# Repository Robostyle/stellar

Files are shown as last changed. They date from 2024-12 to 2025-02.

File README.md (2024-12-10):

<picture>
    Stellar logo
</picture>

# Stellar split Keyboard

- Onshape model can be found [here](https://cad.onshape.com/documents/9f0ec04623bf66083821a7a0/w/c0bdf5da89aae74babc87fd1/e/22223dd23d8e8db672986c41)

# TODO

## PCB

- revision/made text is mirrored on `laR`.
- add silkscreen text for identifying the key, e.g. SW1, etc.
- set rotation on pinky to 10° instead to 5°.
- move the extra row next to the pinky column a bit up (next to the homerow?).

## Inspiration

- https://github.com/urob/zmk-config

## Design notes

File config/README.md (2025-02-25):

# Stellar ZMK firmware

## Building the firmware

The Stellar keyboard uses [ZMK](https://zmk.dev/) firmware which is powered by the [Zephyr :tm: Project ](https://zephyrproject.org/) Real Time Operating System (RTOS).

There are two ways to build, either through a GitHub action, or with a local toolchain.

### Local builds

To build the firmware, see the instructions under the "Development' section. You need to setup ZMK by following the instructions under "Native" [here](https://zmk.dev/docs/development/local-toolchain/setup/native). This only needs to be done once, if you leave the Python virtual environment, source the virtual environment again. 

The actual instructions to build and flash can be found under the section "Building and Flashing" page [here](https://zmk.dev/docs/development/local-toolchain/build-flash). Since this is an external module, follow the instructions under "Building from `zmk-config` Folder".

The TL;DR is (consult the above documentation if this does not work):

Open Zephyr's Getting Started Guide and follow the instructions under these sections:

- [Select and Update OS](https://docs.zephyrproject.org/3.5.0/develop/getting_started/index.html#select-and-update-os)
- [Install Dependencies](https://docs.zephyrproject.org/3.5.0/develop/getting_started/index.html#install-dependencies), for users not using an Ubuntu based distribution, follow the
instructions on the [Install Linux Host Dependencies](https://docs.zephyrproject.org/3.5.0/develop/getting_started/installation_linux.html) page.

Clone the repository:

`git clone git@github.com:Robostyle/stellar.git`

After cloning, you can make the firmware with:

```bash
make 
```

This will build the firmware and place the output in `firmware`.

### Development

In case you like to modify the code, you can perform incremental builds with:

```bash
make build
```

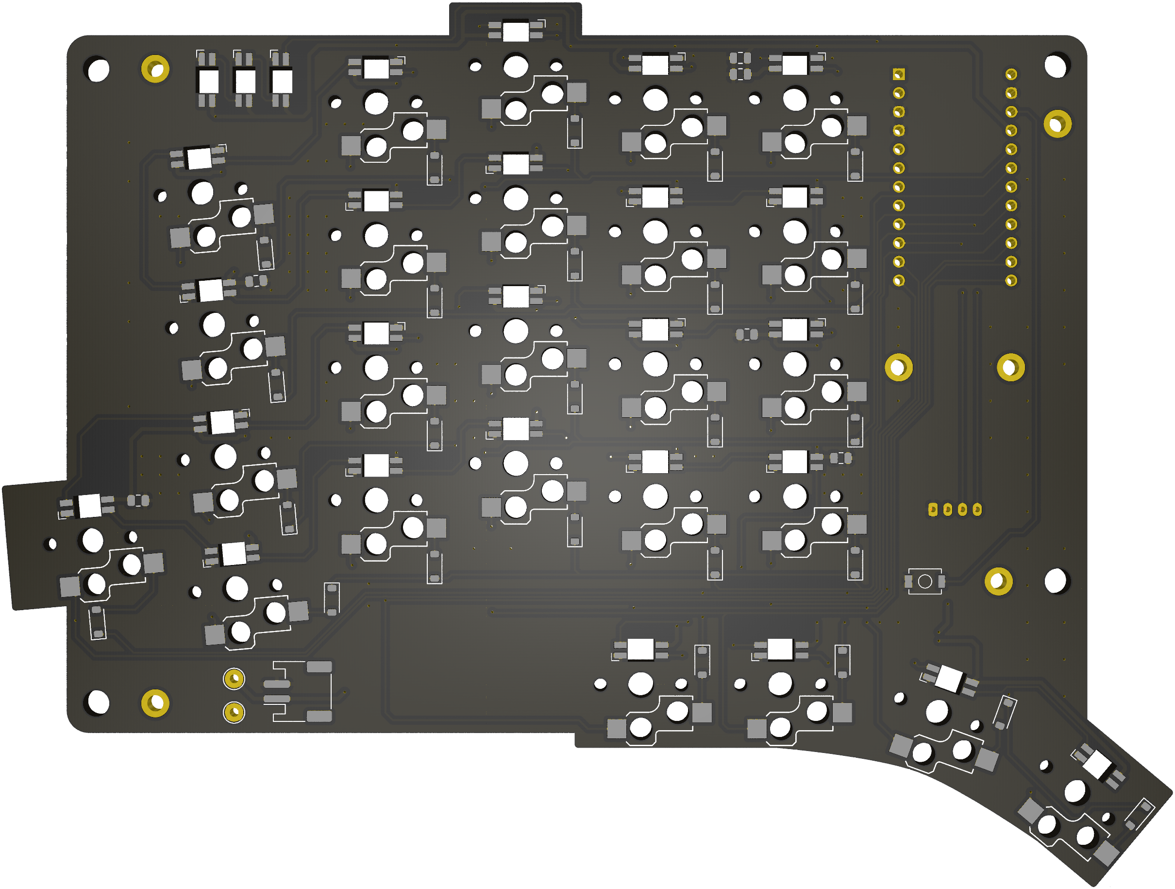
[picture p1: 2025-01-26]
docs/images/stellar-pcb-right-bottom.png

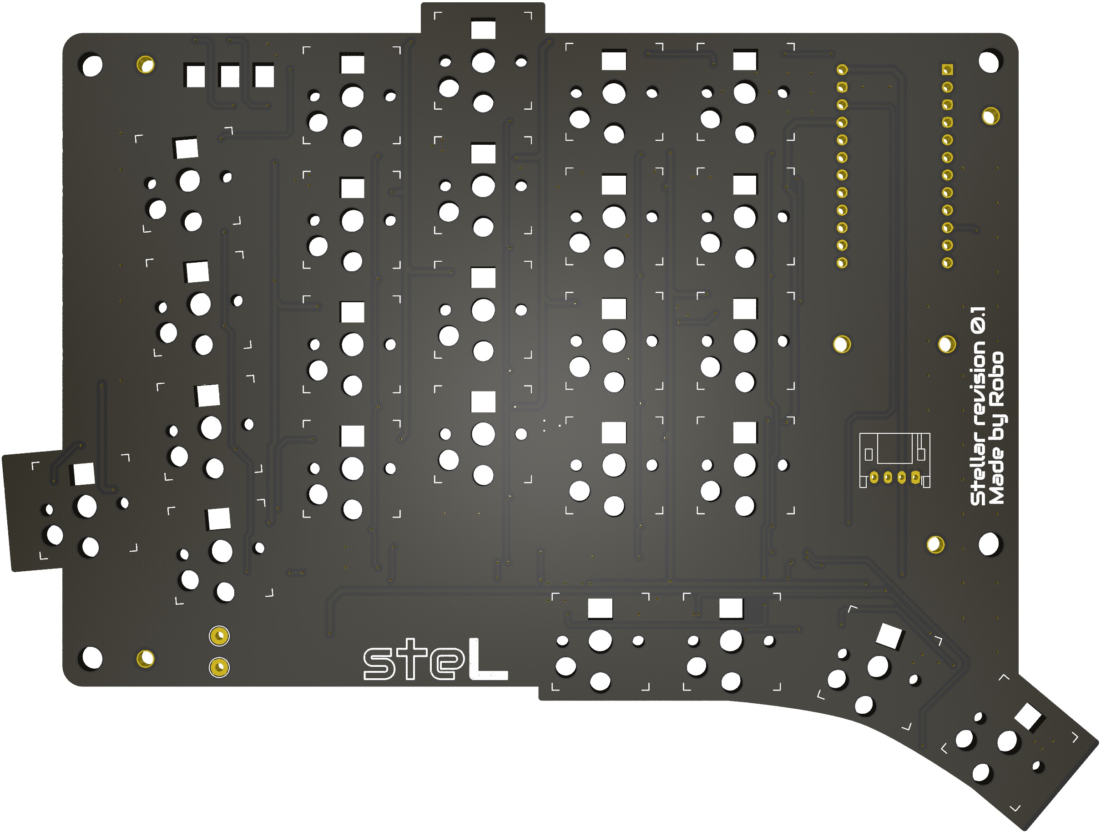
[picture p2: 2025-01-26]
docs/images/stellar-pcb-left-top.png

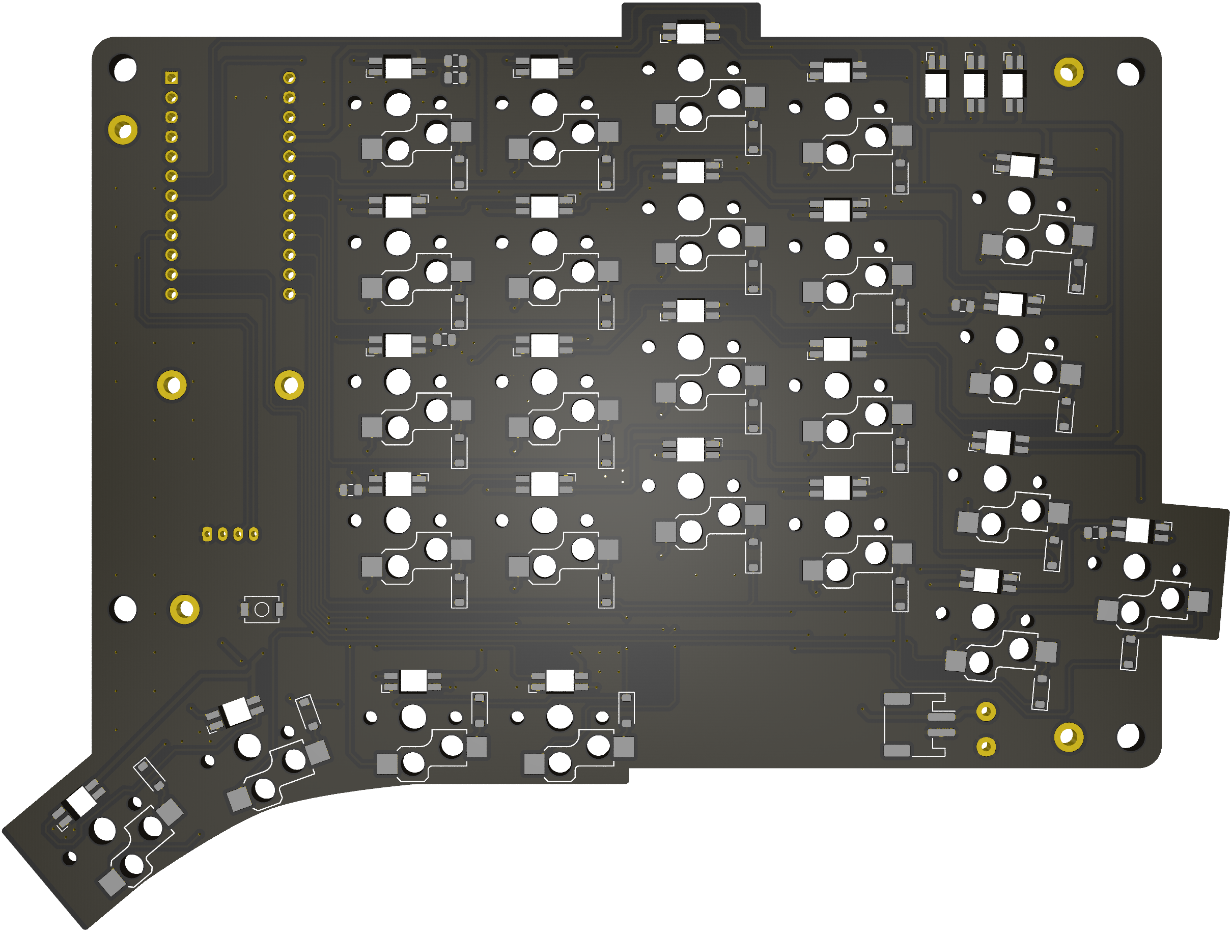
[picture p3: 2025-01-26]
docs/images/stellar-pcb-left-bottom.png

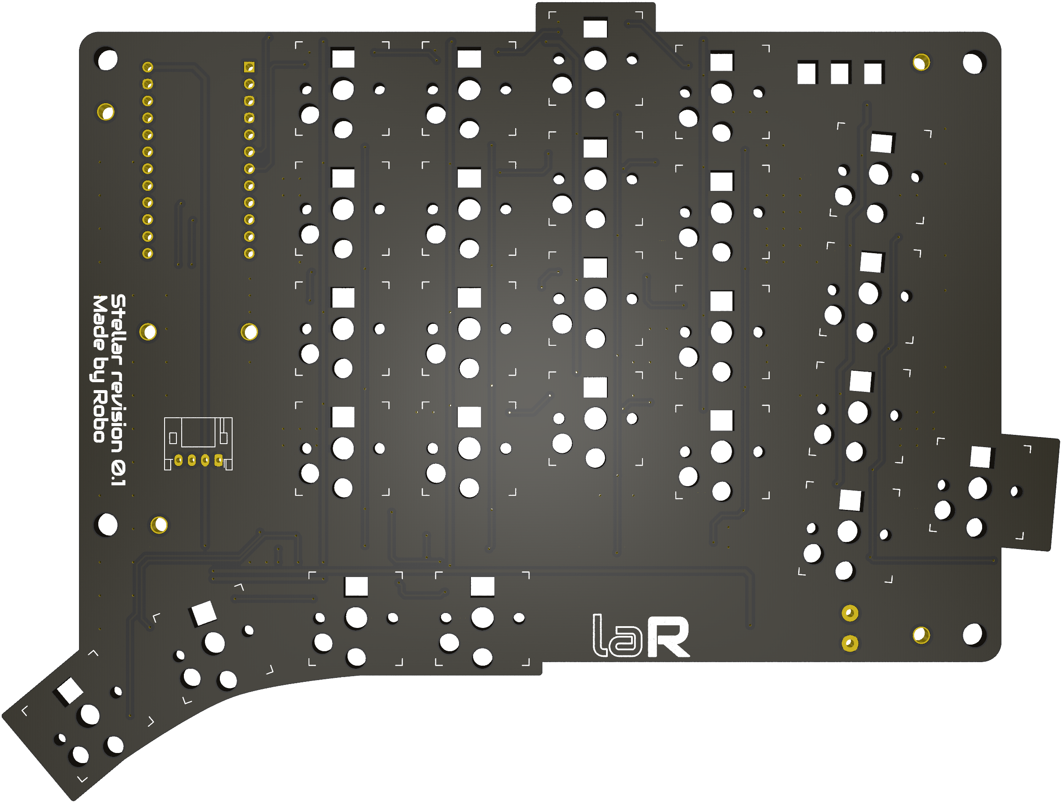
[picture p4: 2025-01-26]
docs/images/stellar-pcb-right-top.png

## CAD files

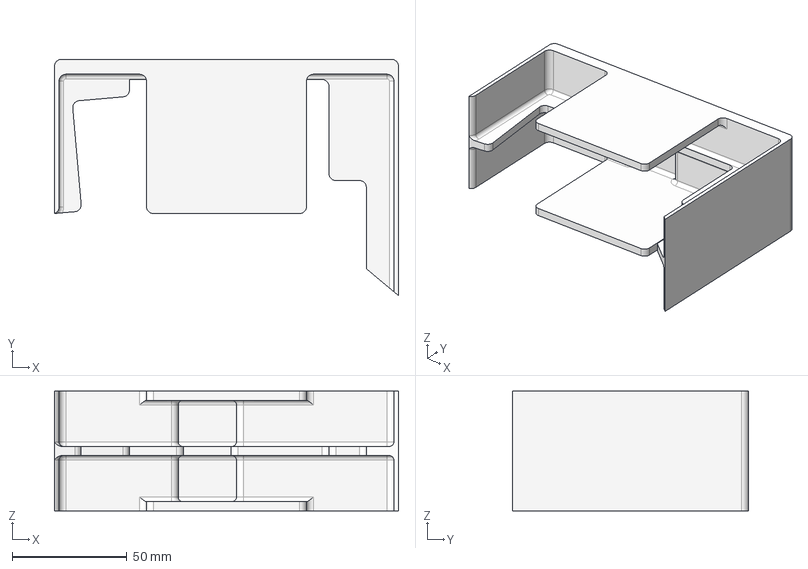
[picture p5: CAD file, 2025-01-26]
case/keyboard_case.step
149.6 x 102.8 x 52.0 mm

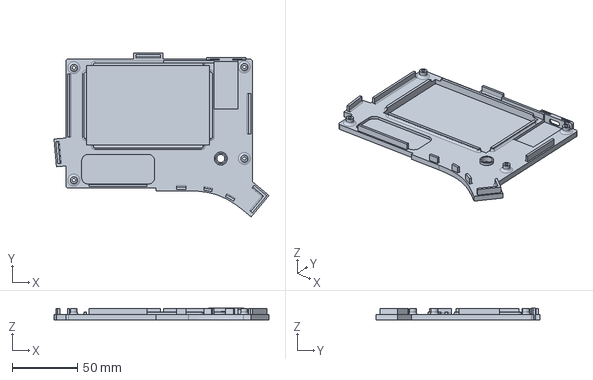
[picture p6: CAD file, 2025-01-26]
case/left/bottom_plate_left.step
164.4 x 125.2 x 8.80 mm

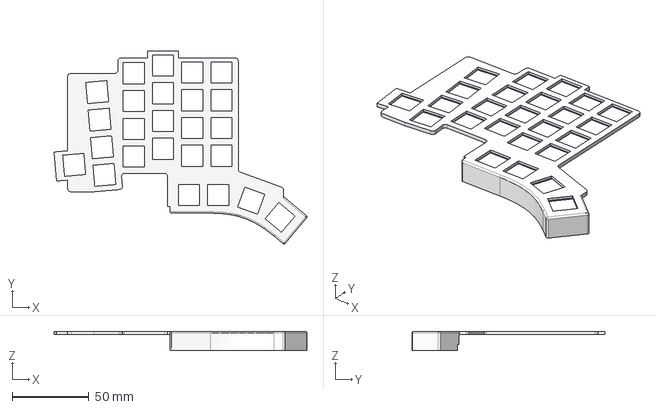
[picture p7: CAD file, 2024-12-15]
case/left/key_plate_left.step
164.4 x 125.4 x 12.6 mm

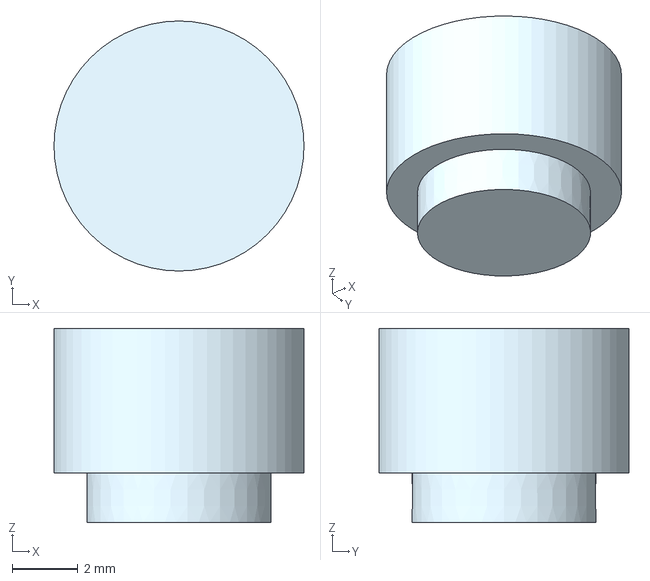
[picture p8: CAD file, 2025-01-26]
case/reset_button_knob.step
7.60 x 7.60 x 5.91 mm

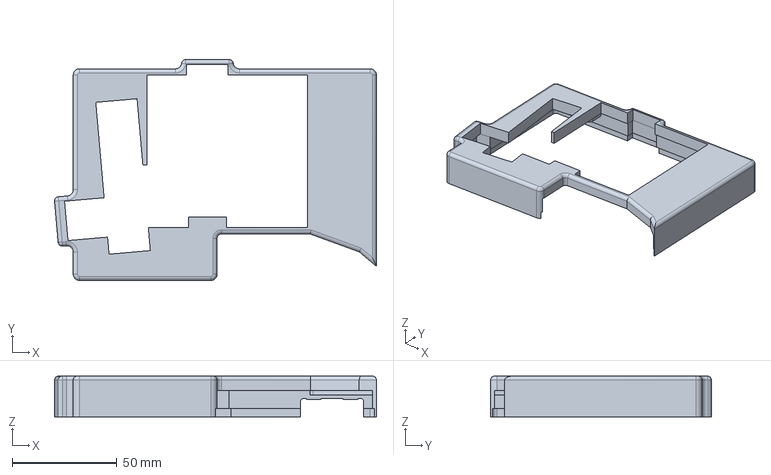
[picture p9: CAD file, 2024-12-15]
case/left/key_frame_left.step
154.0 x 105.7 x 19.6 mm

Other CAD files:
case/right/bottom_plate_right.step
case/right/key_plate_right.step
case/right/key_frame_right.step

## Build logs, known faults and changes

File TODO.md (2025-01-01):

# TODO

* Adding soft off to the keyboard, [see](https://zmk.dev/docs/development/hardware-integration/soft-off-setup)
* Sleep, and power states
* ZMK studio?
* Display?
* Status LEDs
*

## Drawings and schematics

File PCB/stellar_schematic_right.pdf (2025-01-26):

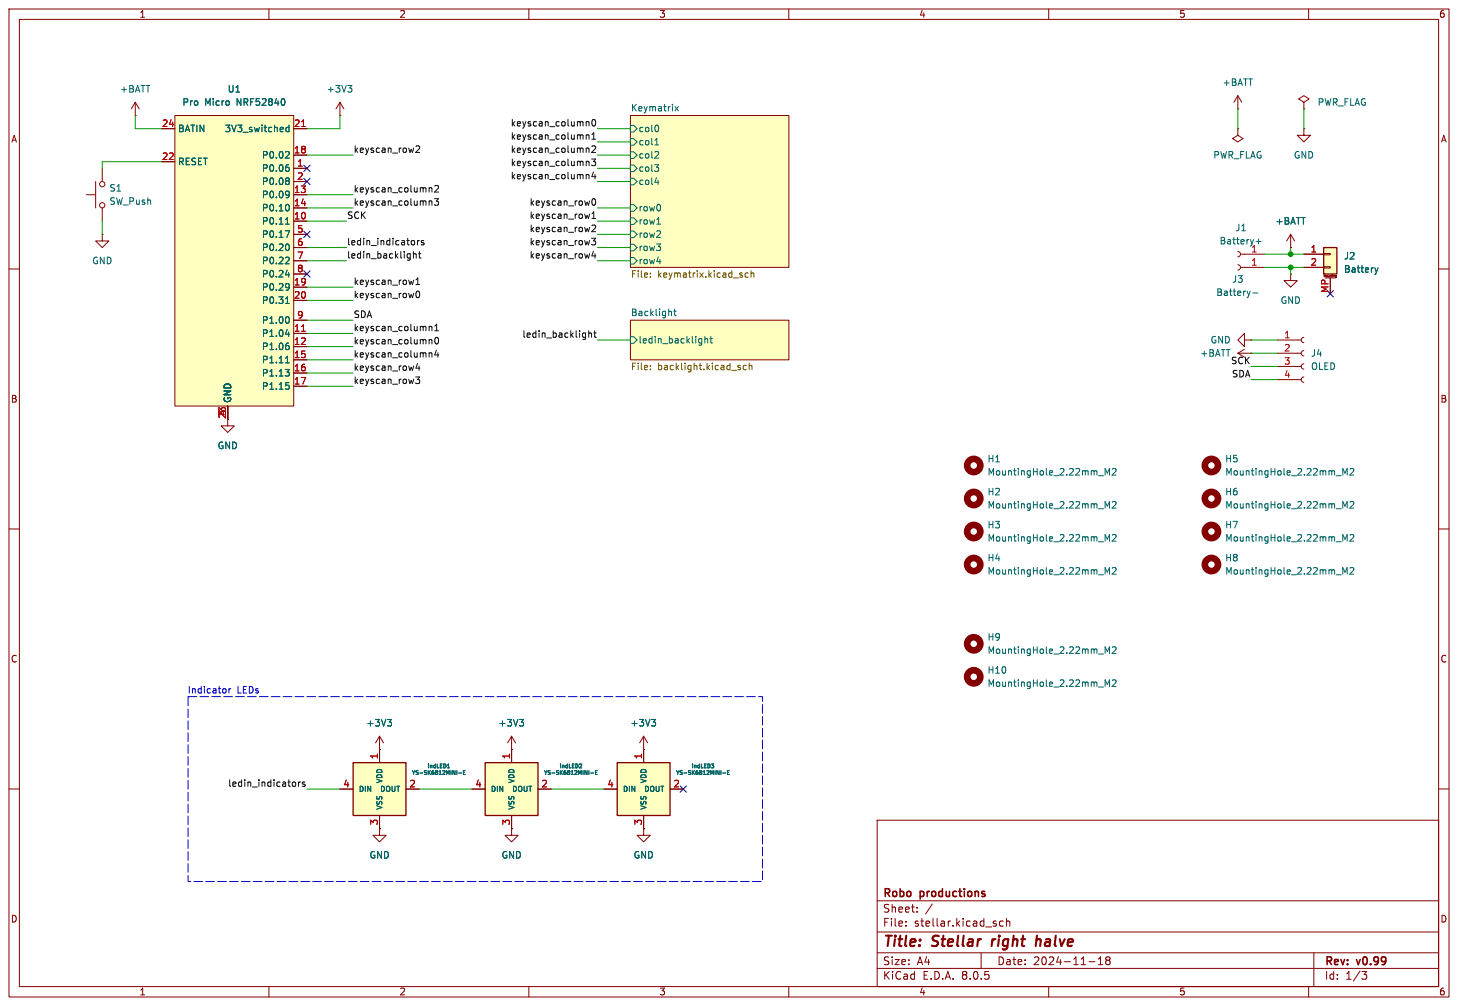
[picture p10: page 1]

1 DOUT 2 VSS 3 DIN 4 GND

Id: 1/3 Title: Stellar right halve

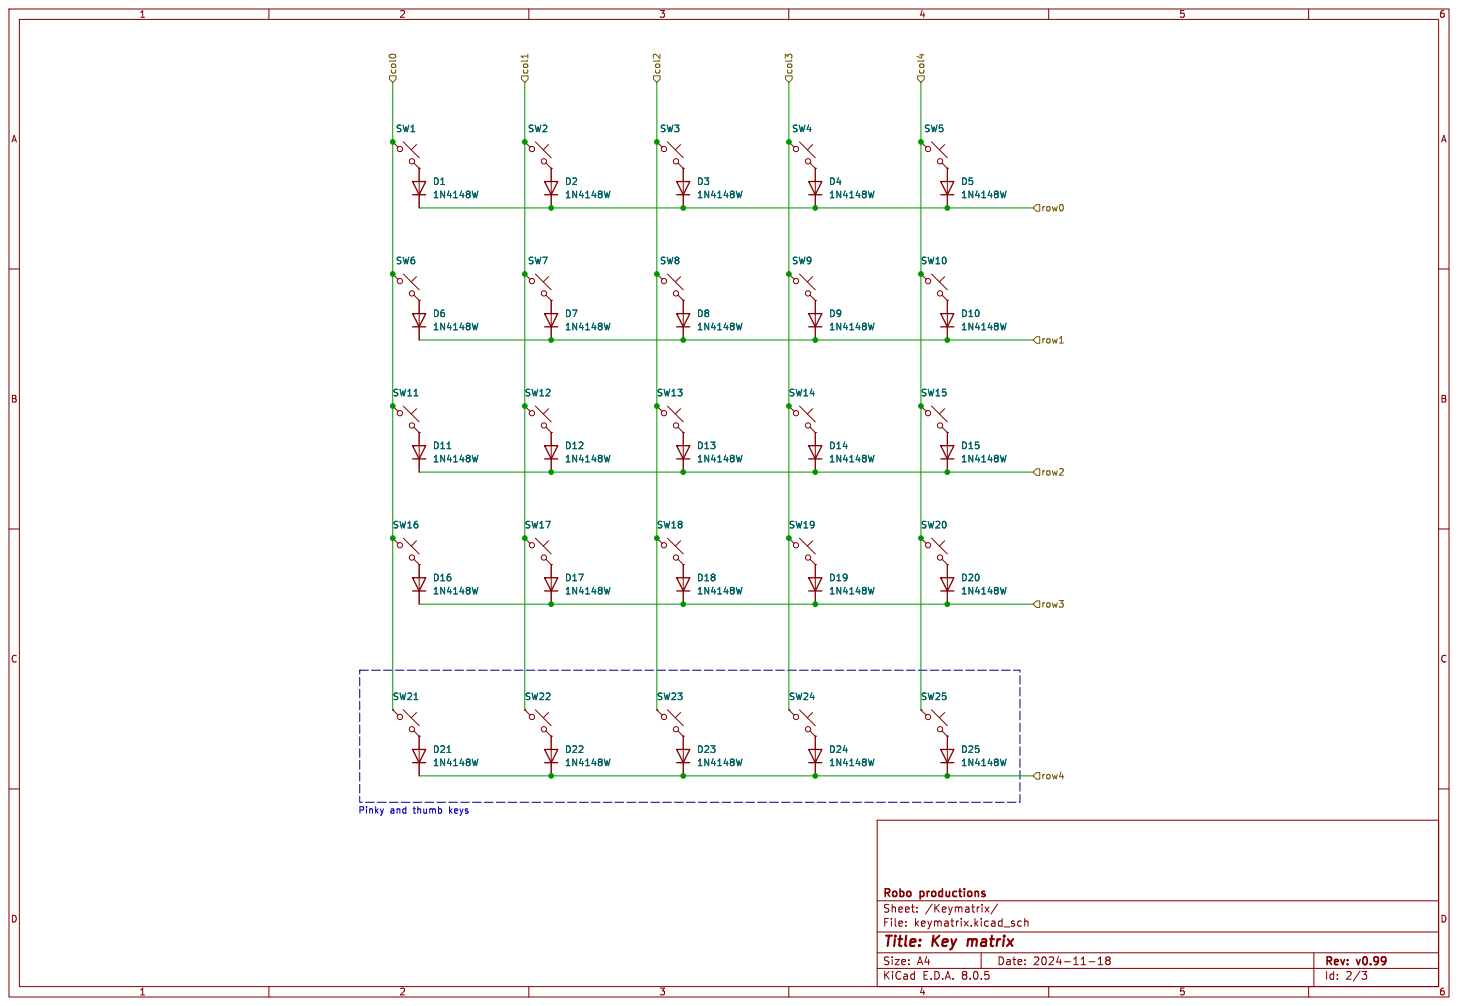
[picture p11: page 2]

Id: 2/3 Title: Key matrix

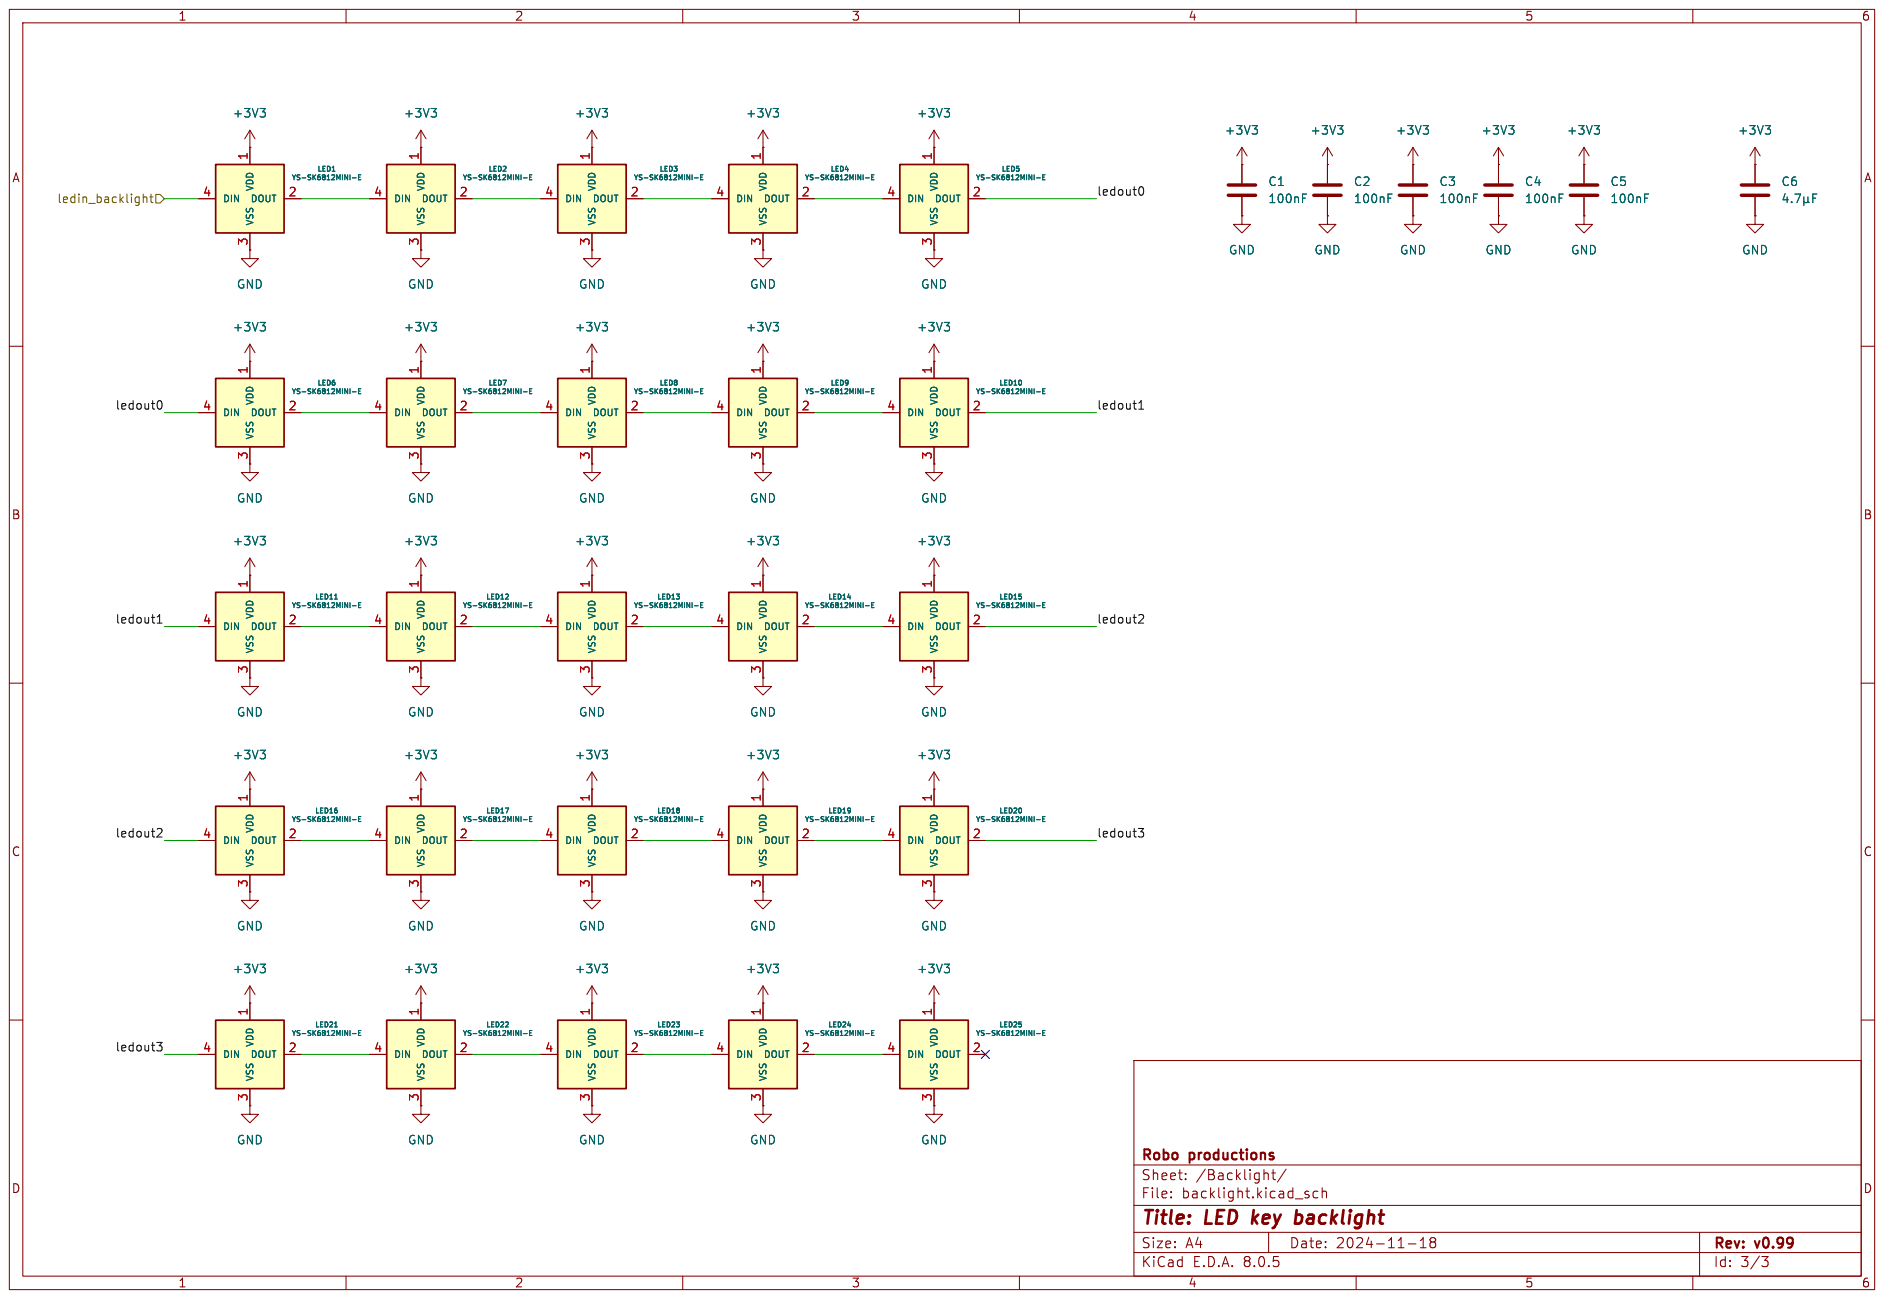
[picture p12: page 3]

1 DOUT 2 VSS 3 DIN 4 +3V3 GND GND

1 DOUT 2 VSS 3 DIN 4 +3V3 GND

1 DOUT 2 VSS 3 DIN 4 GND

1 DOUT 2 VSS 3 DIN 4 GND GND

LED20 YS-SK6812MINI-E +3V3 GNDVDD

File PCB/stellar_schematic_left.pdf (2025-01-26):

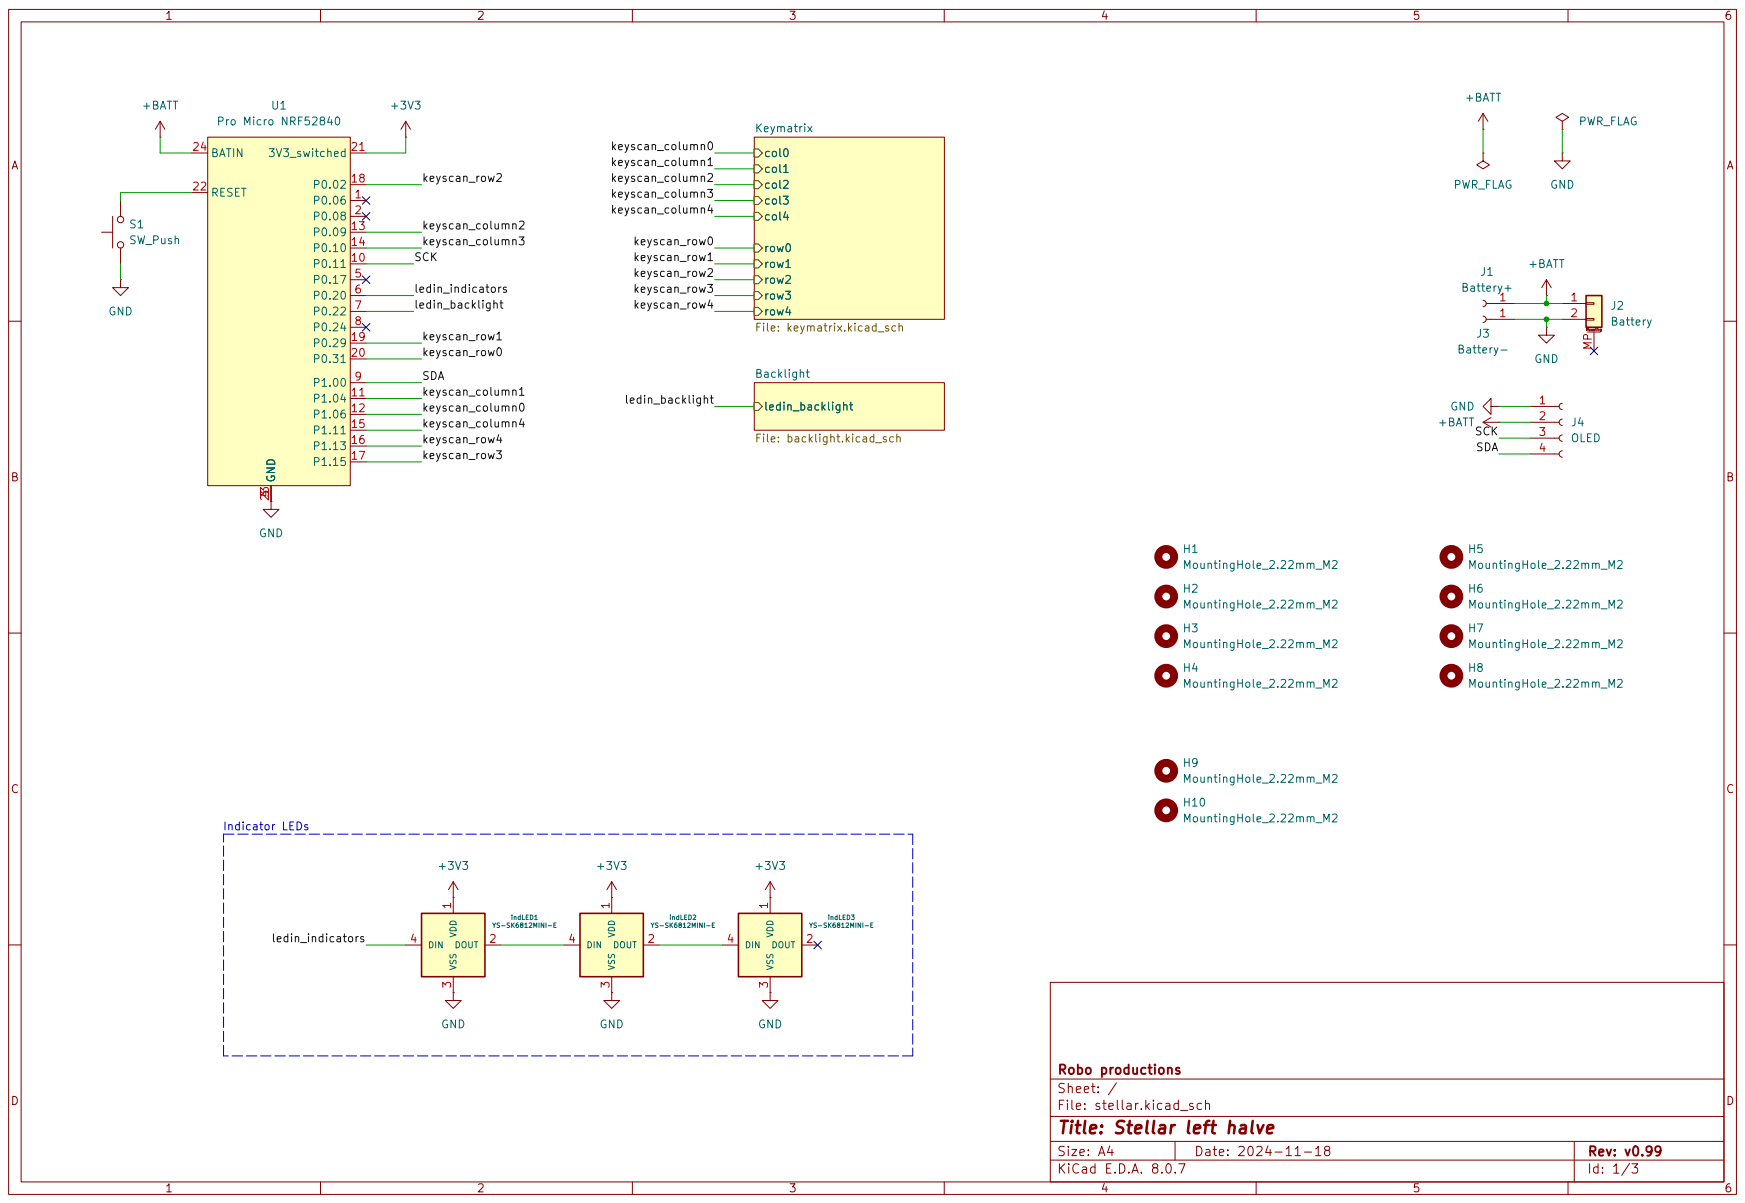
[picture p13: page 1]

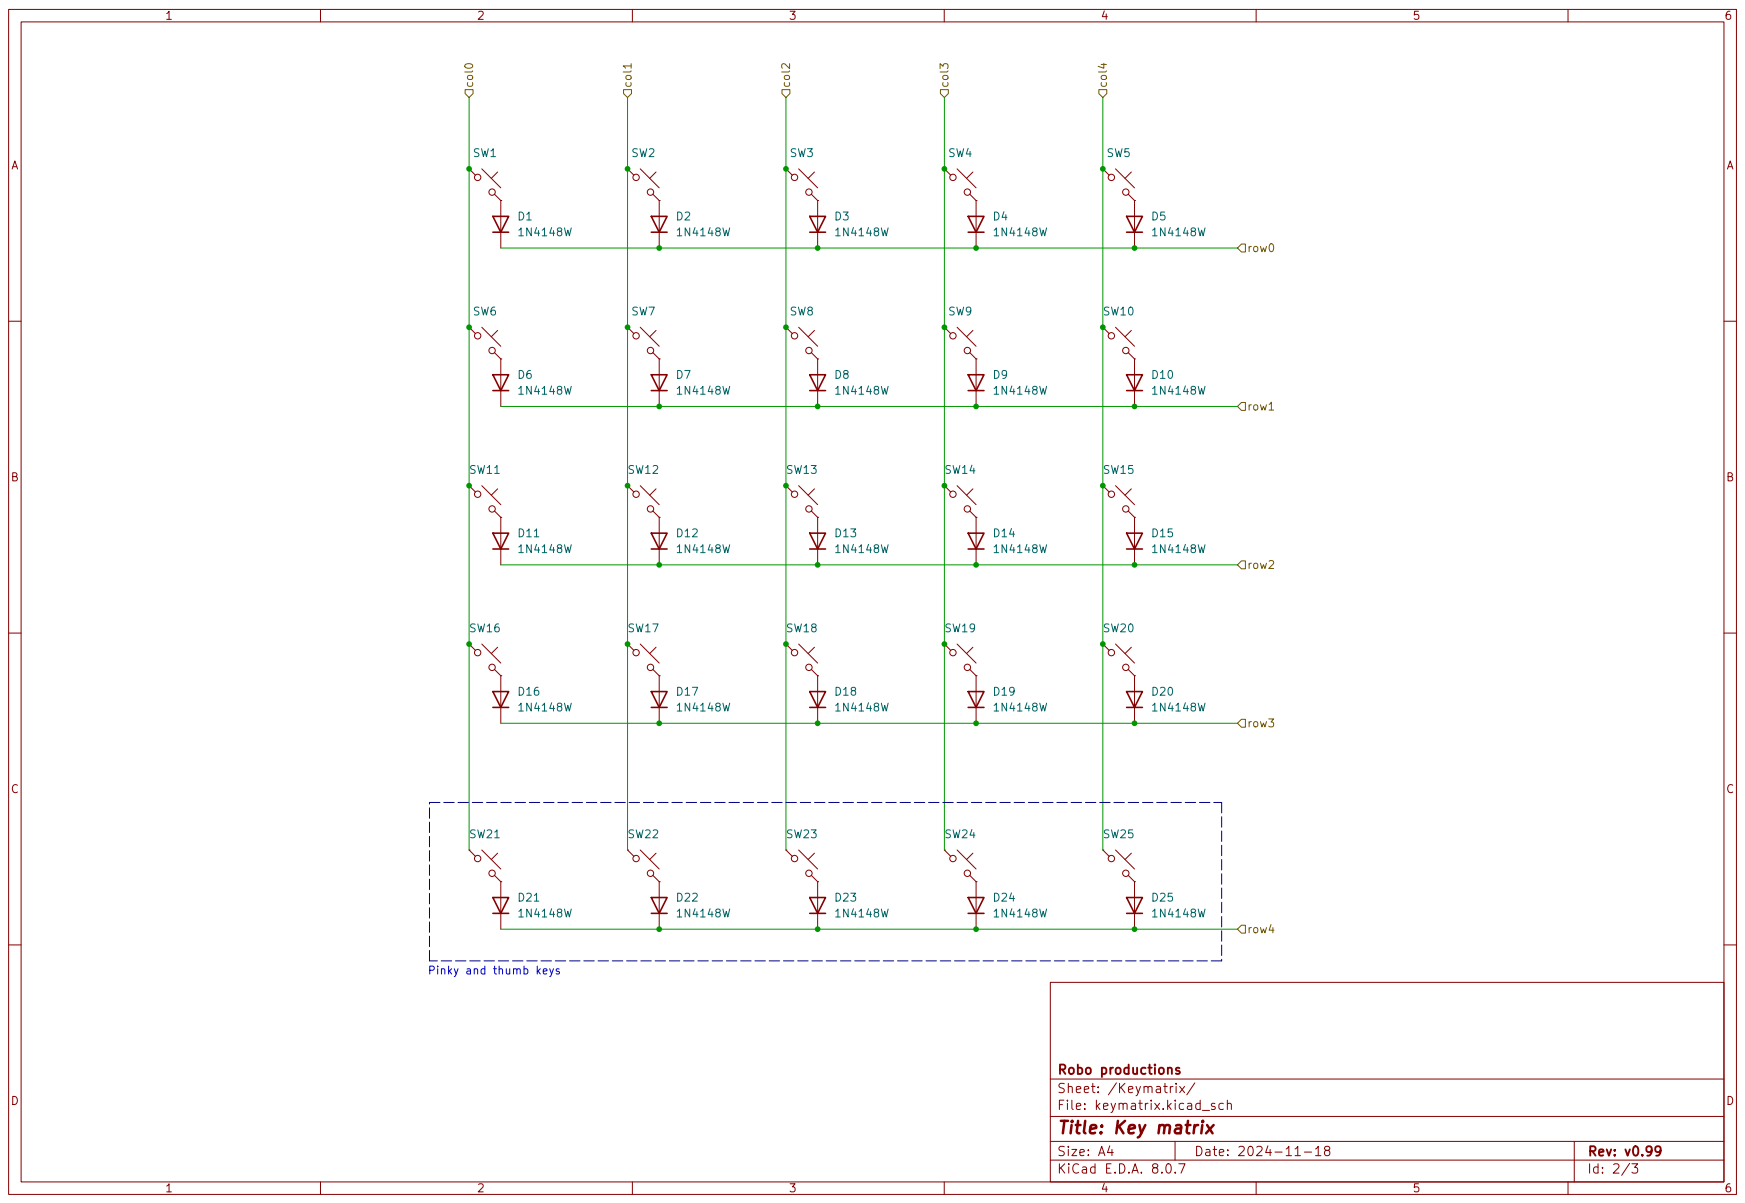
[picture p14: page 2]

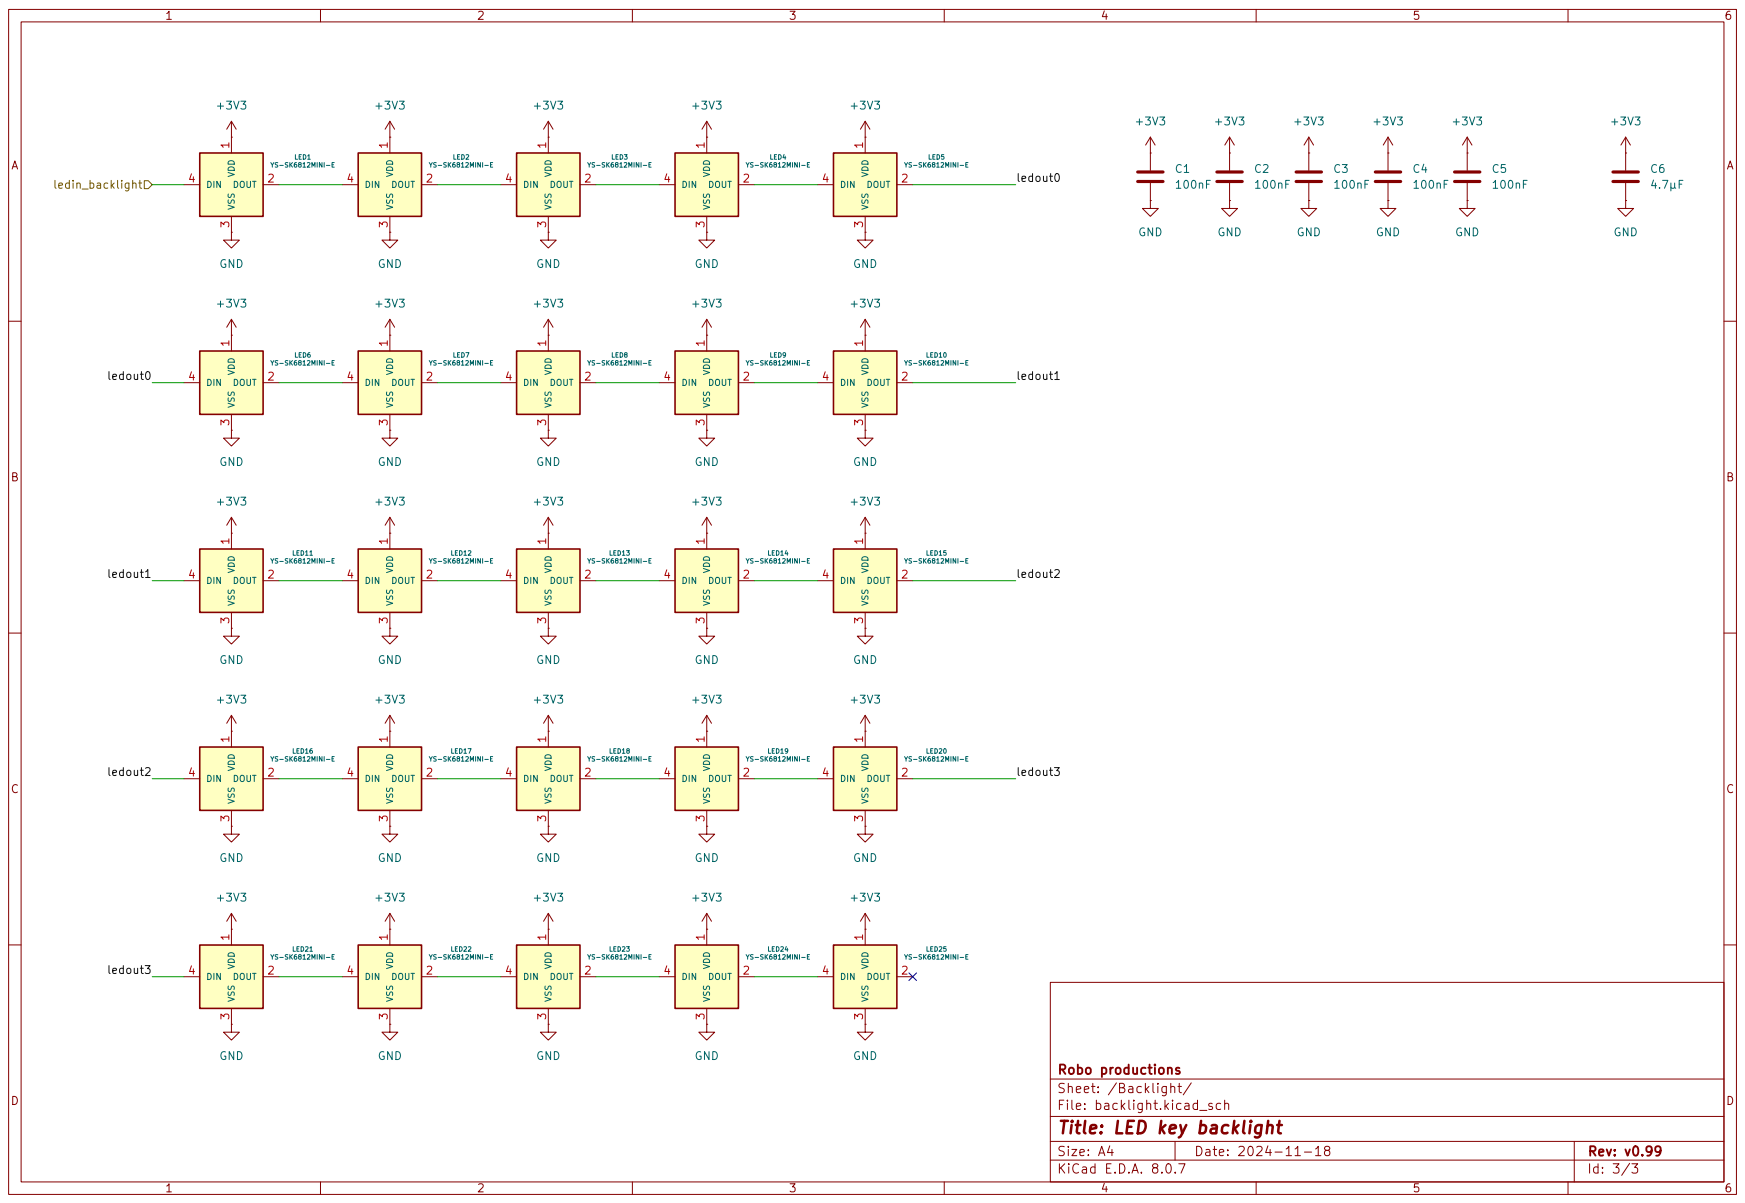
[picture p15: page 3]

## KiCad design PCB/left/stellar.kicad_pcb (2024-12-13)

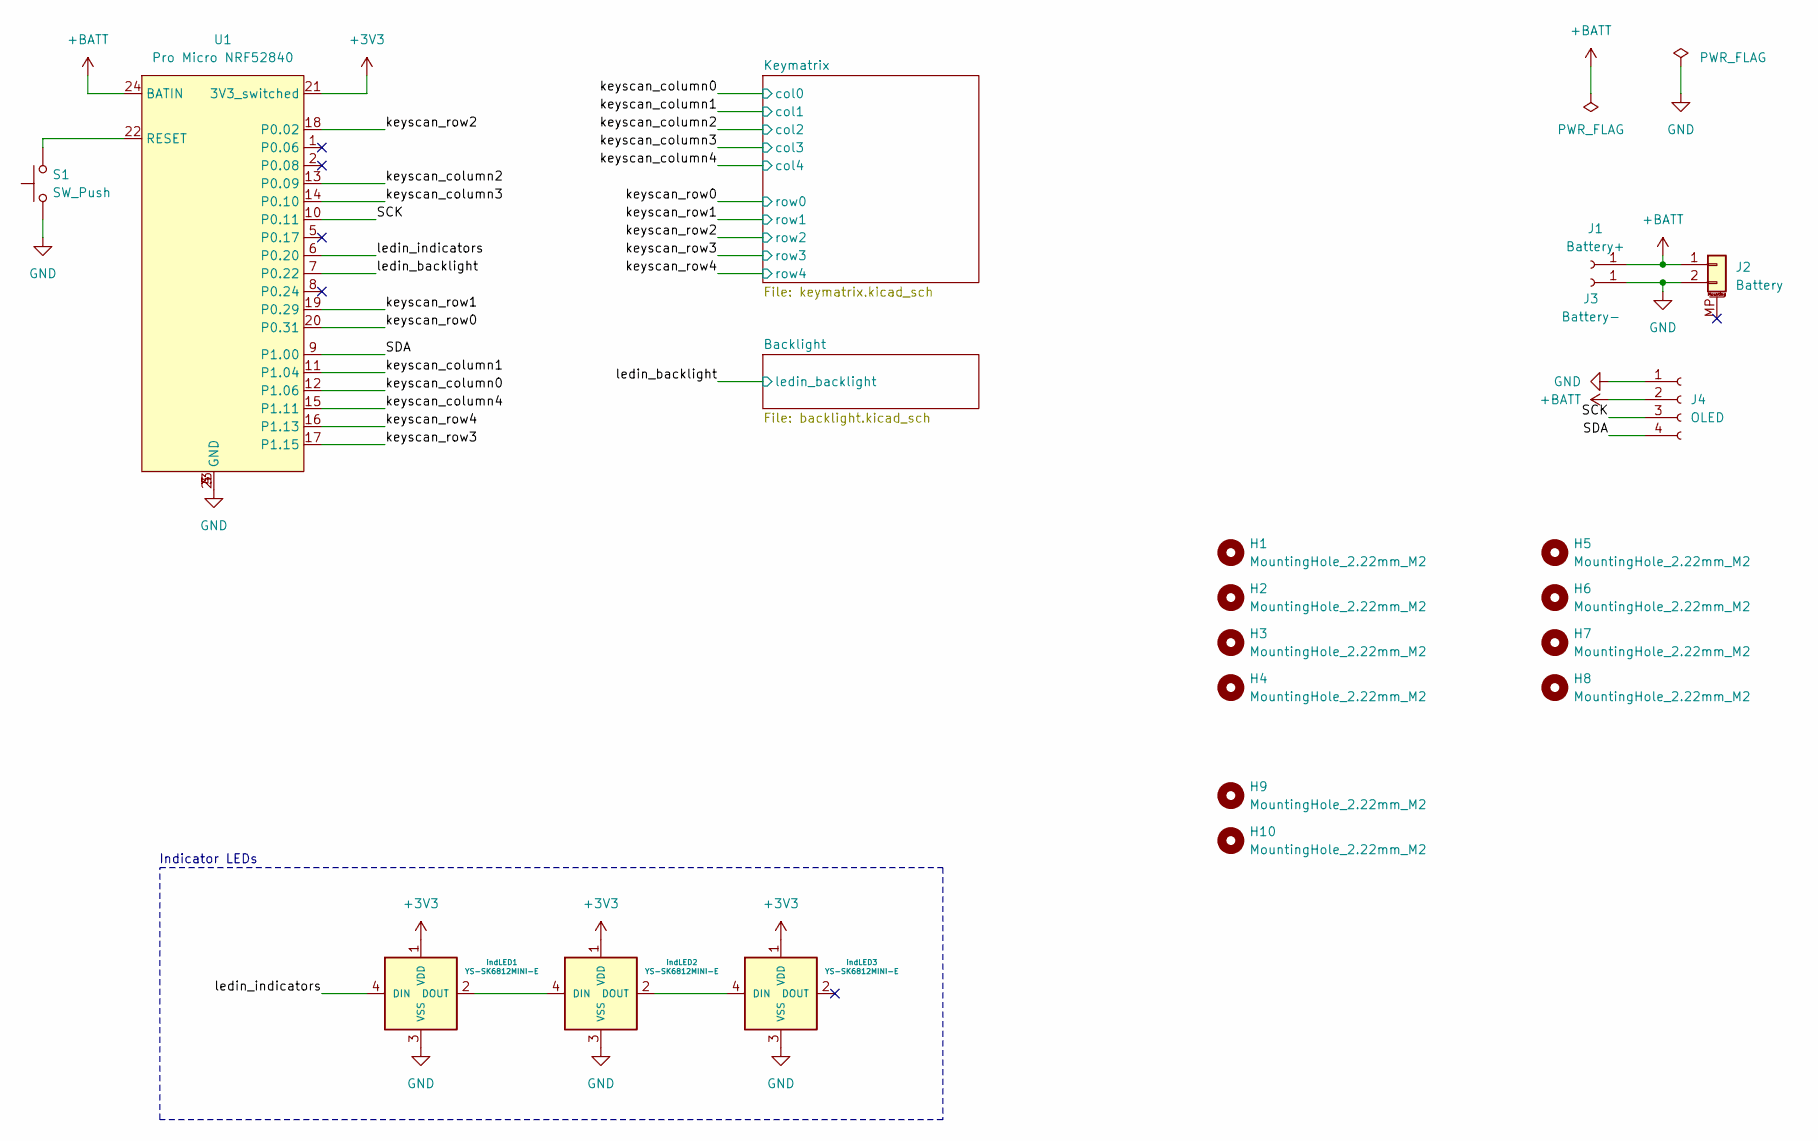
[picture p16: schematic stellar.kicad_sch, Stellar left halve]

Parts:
H1, H2, H3, H4, H9, H10: MountingHole_2.22mm_M2; MountingHole_2.2mm_M2_DIN965_Pad_TopOnly
H5, H6, H7, H8: MountingHole_2.22mm_M2; MountingHole_3.5mm
J1: Battery+; TestPoint_THTPad_D2.5mm_Drill1.2mm
J2: Battery; JST_PH_S2B-PH-SM4-TB_1x02-1MP_P2.00mm_Horizontal
J3: Battery-; TestPoint_THTPad_D2.5mm_Drill1.2mm
J4: OLED; JST_PH_S4B-PH-K_1x04_P2.00mm_Horizontal
S1: SW_Push; microswitch_3x4x2mm
U1: Pro Micro NRF52840; ProMicro-NoSilk
indLED1, indLED2, indLED3: YS-SK6812MINI-E

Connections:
+3V3: U1.21 (3V3_switched), indLED1.1 (VDD), indLED2.1 (VDD), indLED3.1 (VDD); also elsewhere on the board
+BATT: J1.1, J2.1, J4.2, U1.24 (BATIN)
/SCK: J4.3, U1.10 (P0.11)
/SDA: J4.4, U1.9 (P1.00)
/keyscan_column0: U1.12 (P1.06); also elsewhere on the board
/keyscan_column1: U1.11 (P1.04); also elsewhere on the board
/keyscan_column2: U1.13 (P0.09); also elsewhere on the board
/keyscan_column3: U1.14 (P0.10); also elsewhere on the board
/keyscan_column4: U1.15 (P1.11); also elsewhere on the board
/keyscan_row0: U1.20 (P0.31); also elsewhere on the board
/keyscan_row1: U1.19 (P0.29); also elsewhere on the board
/keyscan_row2: U1.18 (P0.02); also elsewhere on the board
/keyscan_row3: U1.17 (P1.15); also elsewhere on the board
/keyscan_row4: U1.16 (P1.13); also elsewhere on the board
/ledin_backlight: U1.7 (P0.22); also elsewhere on the board
/ledin_indicators: U1.6 (P0.20), indLED1.4 (DIN)
GND: J2.2, J3.1, J4.1, S1.1, U1.3 (GND), U1.4 (GND), U1.23 (GND), indLED1.3 (VSS), indLED2.3 (VSS), indLED3.3 (VSS); also elsewhere on the board
unnamed: S1.2, U1.22 (RESET)
unnamed: indLED1.2 (DOUT), indLED2.4 (DIN)
unnamed: indLED2.2 (DOUT), indLED3.4 (DIN)

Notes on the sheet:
Indicator LEDs

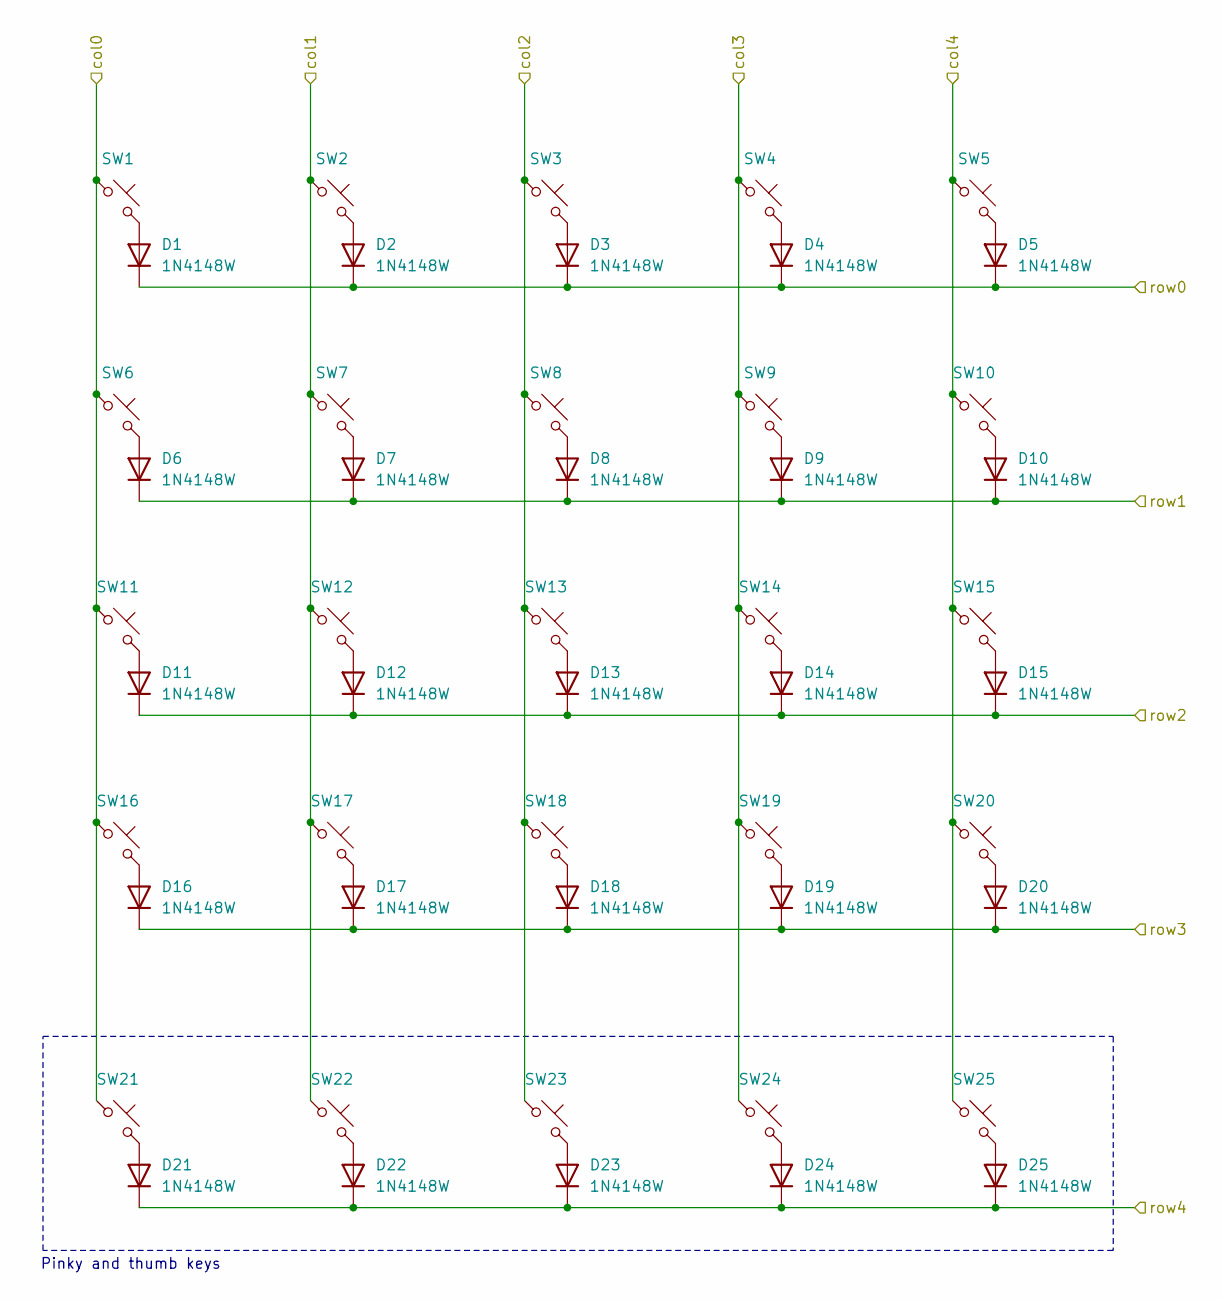
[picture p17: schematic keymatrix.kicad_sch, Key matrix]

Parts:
D1, D2, D3, D4, D5, D6, D7, D8, D9, D10, D11, D12, D13, D14, D15, D16, D17, D18, D19, D20, D21, D22, D23, D24, D25: 1N4148W; D_SOD-123
SW1, SW2, SW3, SW4, SW5, SW6, SW7, SW8, SW9, SW10, SW11, SW12, SW13, SW14, SW15, SW16, SW17, SW18, SW19, SW20, SW21, SW22, SW23, SW24, SW25: SW_Push_45deg; Kailh_socket_PG1350

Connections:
/keyscan_column0: SW1.1, SW6.1, SW11.1, SW16.1, SW21.1; also elsewhere on the board
/keyscan_column1: SW2.1, SW7.1, SW12.1, SW17.1, SW22.1; also elsewhere on the board
/keyscan_column2: SW3.1, SW8.1, SW13.1, SW18.1, SW23.1; also elsewhere on the board
/keyscan_column3: SW4.1, SW9.1, SW14.1, SW19.1, SW24.1; also elsewhere on the board
/keyscan_column4: SW5.1, SW10.1, SW15.1, SW20.1, SW25.1; also elsewhere on the board
/keyscan_row0: D1.1 (K), D2.1 (K), D3.1 (K), D4.1 (K), D5.1 (K); also elsewhere on the board
/keyscan_row1: D6.1 (K), D7.1 (K), D8.1 (K), D9.1 (K), D10.1 (K); also elsewhere on the board
/keyscan_row2: D11.1 (K), D12.1 (K), D13.1 (K), D14.1 (K), D15.1 (K); also elsewhere on the board
/keyscan_row3: D16.1 (K), D17.1 (K), D18.1 (K), D19.1 (K), D20.1 (K); also elsewhere on the board
/keyscan_row4: D21.1 (K), D22.1 (K), D23.1 (K), D24.1 (K), D25.1 (K); also elsewhere on the board
unnamed: D1.2 (A), SW1.2
unnamed: D2.2 (A), SW2.2
unnamed: D3.2 (A), SW3.2
unnamed: D4.2 (A), SW4.2
unnamed: D5.2 (A), SW5.2
unnamed: D6.2 (A), SW6.2
unnamed: D7.2 (A), SW7.2
unnamed: D8.2 (A), SW8.2
unnamed: D9.2 (A), SW9.2
unnamed: D10.2 (A), SW10.2
unnamed: D11.2 (A), SW11.2
unnamed: D12.2 (A), SW12.2
unnamed: D13.2 (A), SW13.2
unnamed: D14.2 (A), SW14.2
unnamed: D15.2 (A), SW15.2
unnamed: D16.2 (A), SW16.2
unnamed: D17.2 (A), SW17.2
unnamed: D18.2 (A), SW18.2
unnamed: D19.2 (A), SW19.2
unnamed: D20.2 (A), SW20.2
unnamed: D21.2 (A), SW21.2
unnamed: D22.2 (A), SW22.2
unnamed: D23.2 (A), SW23.2
unnamed: D24.2 (A), SW24.2
unnamed: D25.2 (A), SW25.2

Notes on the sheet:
Pinky and thumb keys

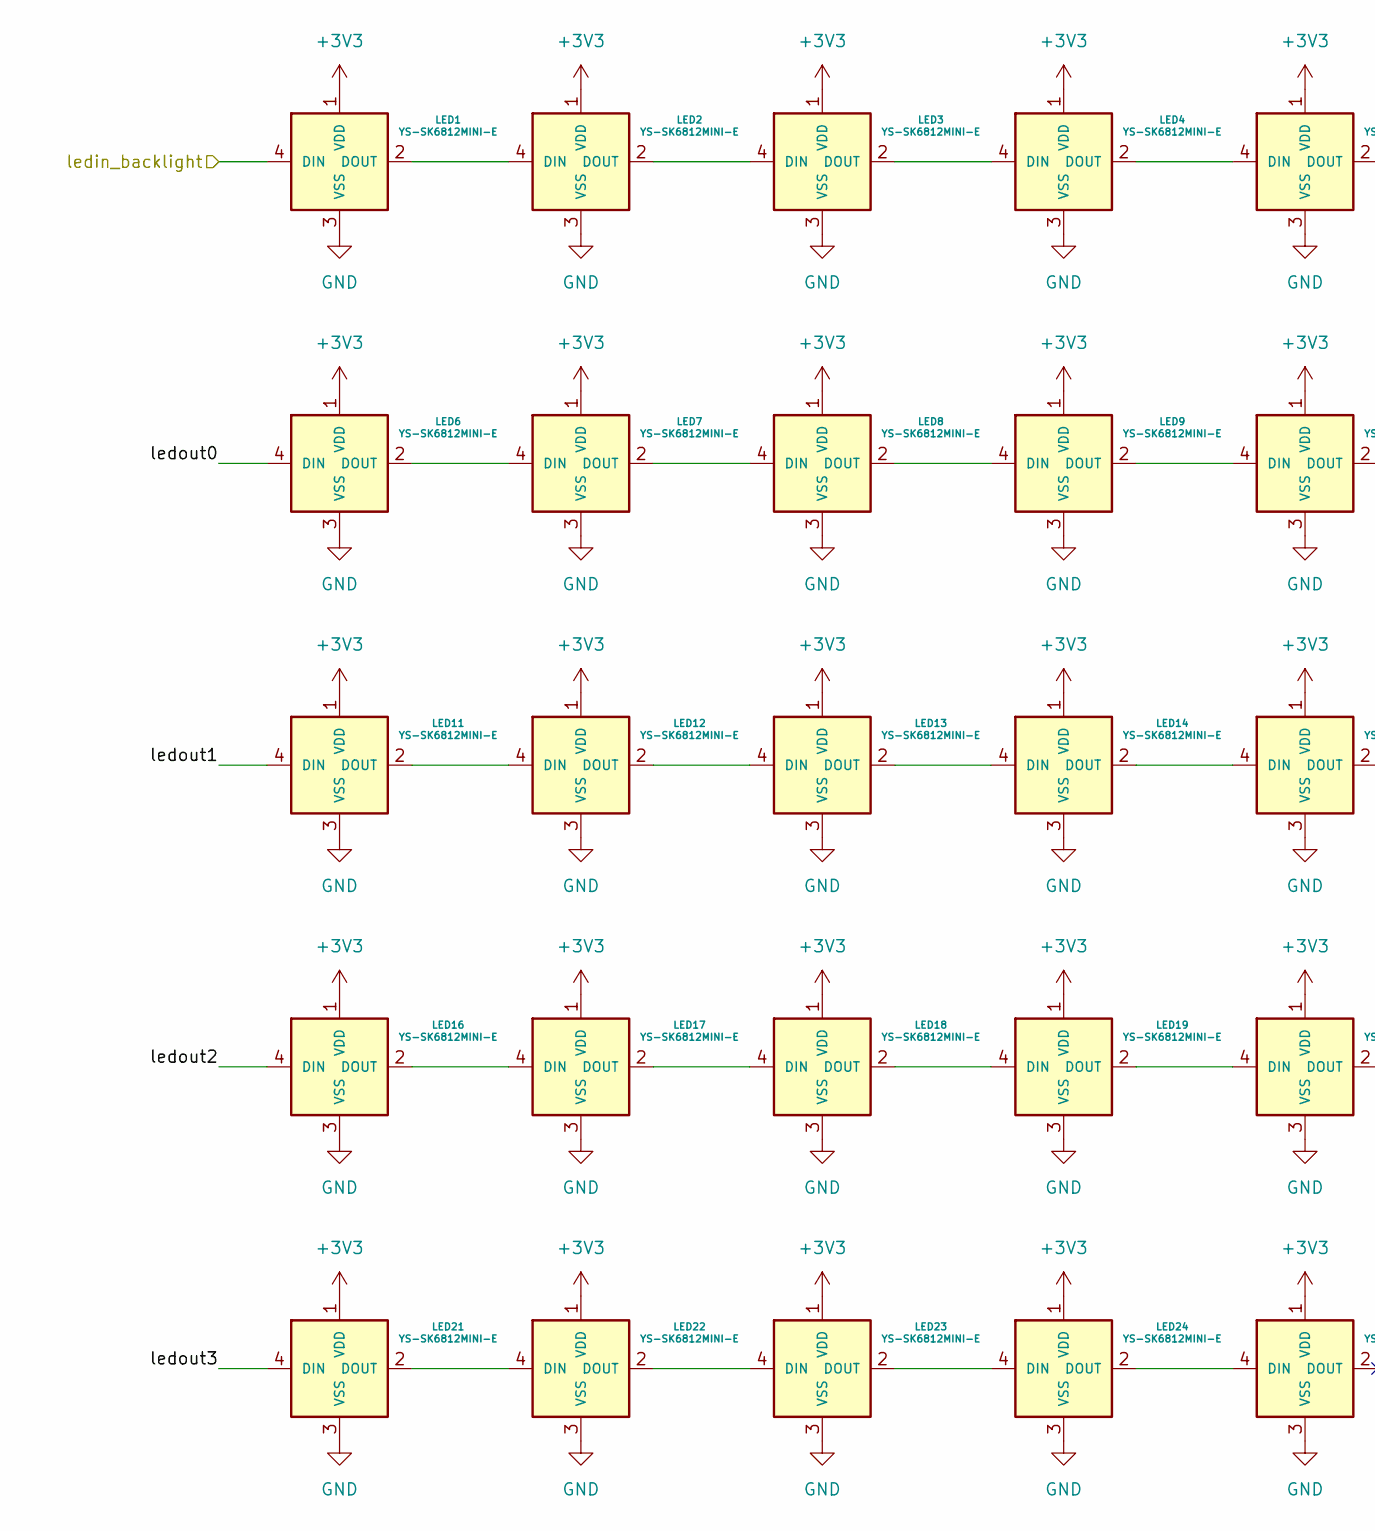
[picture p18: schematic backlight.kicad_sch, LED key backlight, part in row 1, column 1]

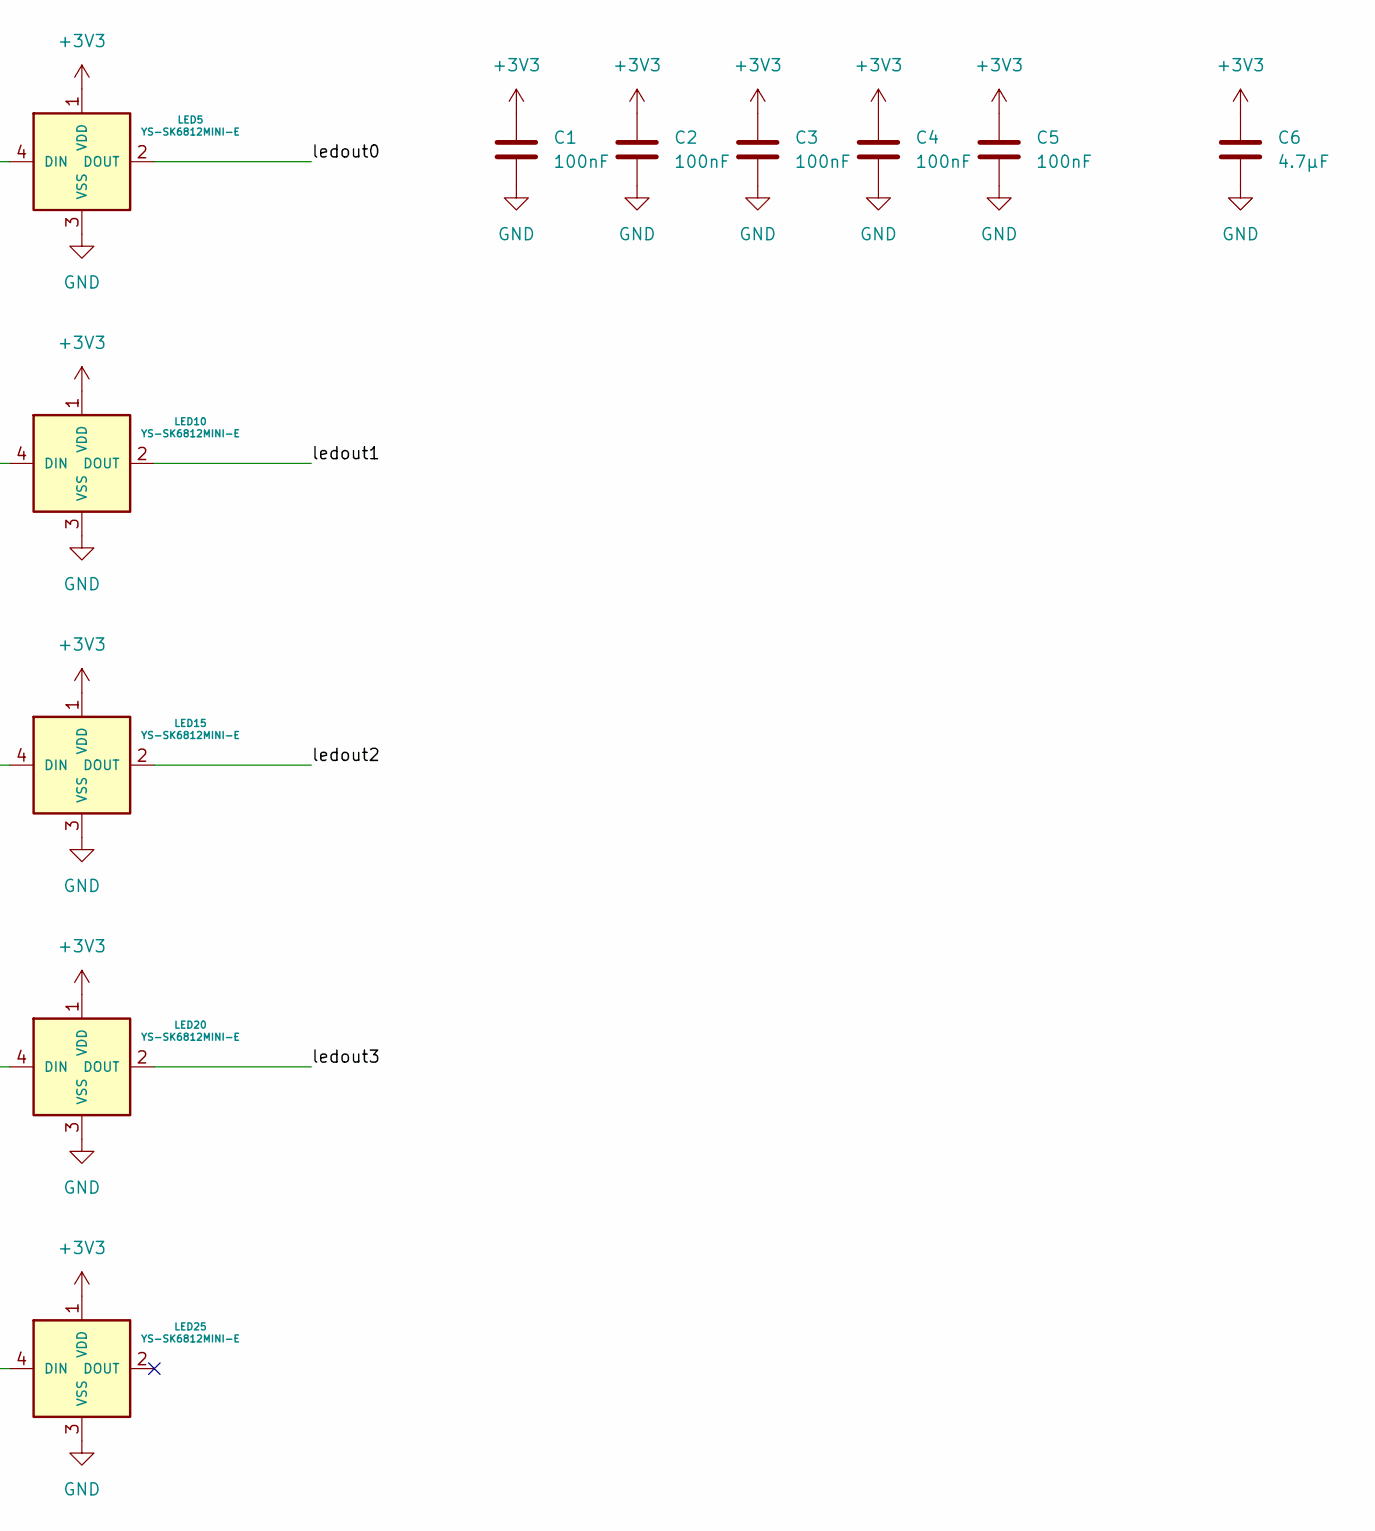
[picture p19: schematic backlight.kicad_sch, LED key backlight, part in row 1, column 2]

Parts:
C1, C2, C3, C4, C5: 100nF; C_0805_2012Metric
C6: 4.7μF; C_0805_2012Metric
LED1, LED2, LED3, LED4, LED5, LED6, LED7, LED8, LED9, LED10, LED11, LED12, LED13, LED14, LED15, LED16, LED17, LED18, LED19, LED20, LED21, LED22, LED23, LED24, LED25: YS-SK6812MINI-E

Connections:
+3V3: C1.1, C2.1, C3.1, C4.1, C5.1, C6.1, LED1.1 (VDD), LED2.1 (VDD), LED3.1 (VDD), LED4.1 (VDD), LED5.1 (VDD), LED6.1 (VDD), LED7.1 (VDD), LED8.1 (VDD), LED9.1 (VDD), LED10.1 (VDD), LED11.1 (VDD), LED12.1 (VDD), LED13.1 (VDD), LED14.1 (VDD), LED15.1 (VDD), LED16.1 (VDD), LED17.1 (VDD), LED18.1 (VDD), LED19.1 (VDD), LED20.1 (VDD), LED21.1 (VDD), LED22.1 (VDD), LED23.1 (VDD), LED24.1 (VDD), LED25.1 (VDD); also elsewhere on the board
/Backlight/ledout0: LED5.2 (DOUT), LED6.4 (DIN)
/Backlight/ledout1: LED10.2 (DOUT), LED11.4 (DIN)
/Backlight/ledout2: LED15.2 (DOUT), LED16.4 (DIN)
/Backlight/ledout3: LED20.2 (DOUT), LED21.4 (DIN)
/ledin_backlight: LED1.4 (DIN); also elsewhere on the board
GND: C1.2, C2.2, C3.2, C4.2, C5.2, C6.2, LED1.3 (VSS), LED2.3 (VSS), LED3.3 (VSS), LED4.3 (VSS), LED5.3 (VSS), LED6.3 (VSS), LED7.3 (VSS), LED8.3 (VSS), LED9.3 (VSS), LED10.3 (VSS), LED11.3 (VSS), LED12.3 (VSS), LED13.3 (VSS), LED14.3 (VSS), LED15.3 (VSS), LED16.3 (VSS), LED17.3 (VSS), LED18.3 (VSS), LED19.3 (VSS), LED20.3 (VSS), LED21.3 (VSS), LED22.3 (VSS), LED23.3 (VSS), LED24.3 (VSS), LED25.3 (VSS); also elsewhere on the board
unnamed: LED1.2 (DOUT), LED2.4 (DIN)
unnamed: LED2.2 (DOUT), LED3.4 (DIN)
unnamed: LED3.2 (DOUT), LED4.4 (DIN)
unnamed: LED4.2 (DOUT), LED5.4 (DIN)
unnamed: LED6.2 (DOUT), LED7.4 (DIN)
unnamed: LED7.2 (DOUT), LED8.4 (DIN)
unnamed: LED8.2 (DOUT), LED9.4 (DIN)
unnamed: LED9.2 (DOUT), LED10.4 (DIN)
unnamed: LED11.2 (DOUT), LED12.4 (DIN)
unnamed: LED12.2 (DOUT), LED13.4 (DIN)
unnamed: LED13.2 (DOUT), LED14.4 (DIN)
unnamed: LED14.2 (DOUT), LED15.4 (DIN)
unnamed: LED16.2 (DOUT), LED17.4 (DIN)
unnamed: LED17.2 (DOUT), LED18.4 (DIN)
unnamed: LED18.2 (DOUT), LED19.4 (DIN)
unnamed: LED19.2 (DOUT), LED20.4 (DIN)
unnamed: LED21.2 (DOUT), LED22.4 (DIN)
unnamed: LED22.2 (DOUT), LED23.4 (DIN)
unnamed: LED23.2 (DOUT), LED24.4 (DIN)
unnamed: LED24.2 (DOUT), LED25.4 (DIN)

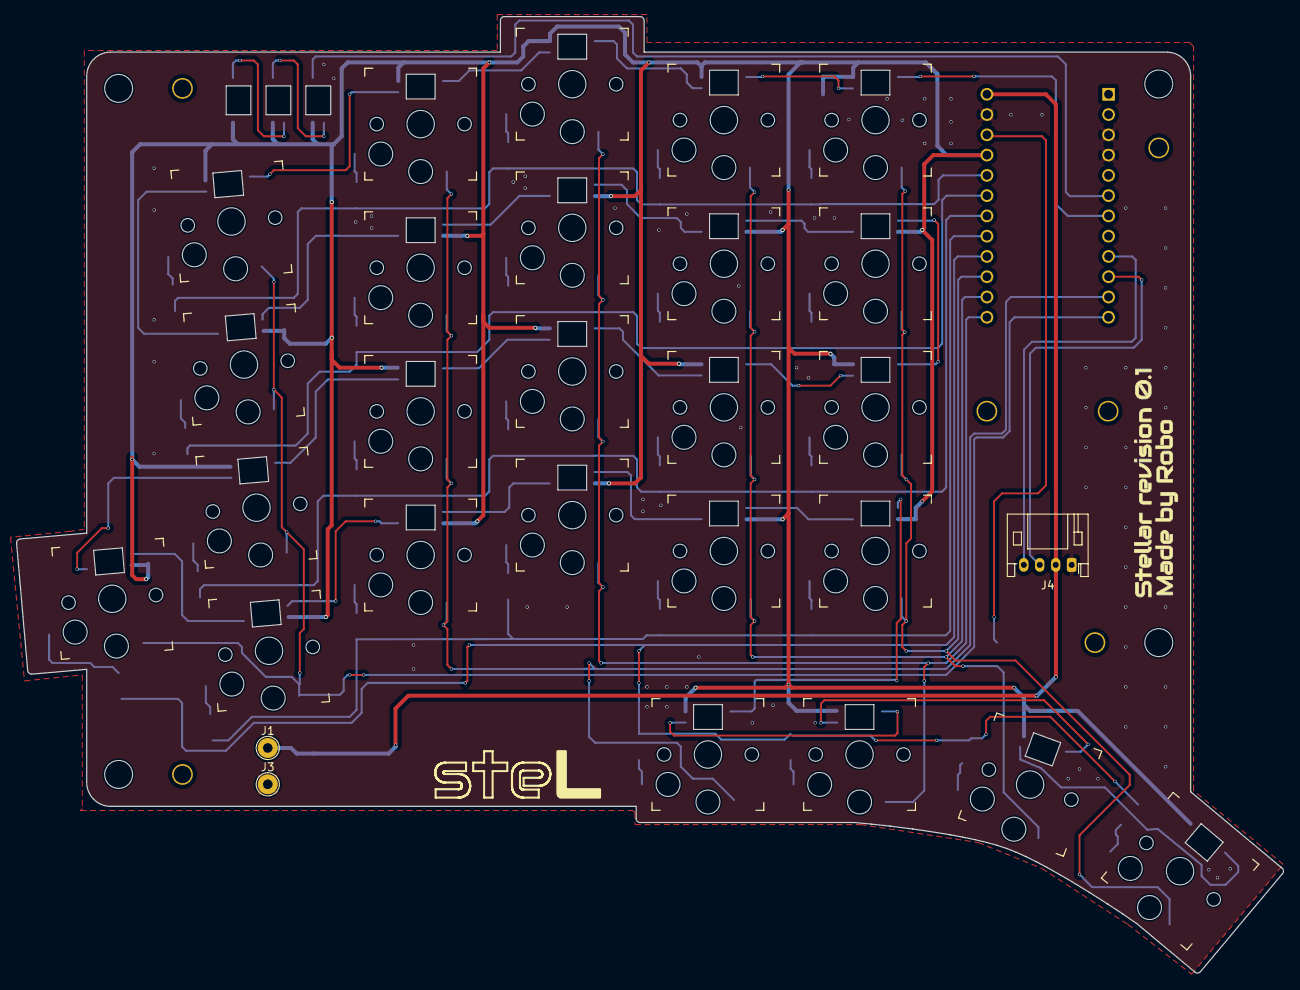
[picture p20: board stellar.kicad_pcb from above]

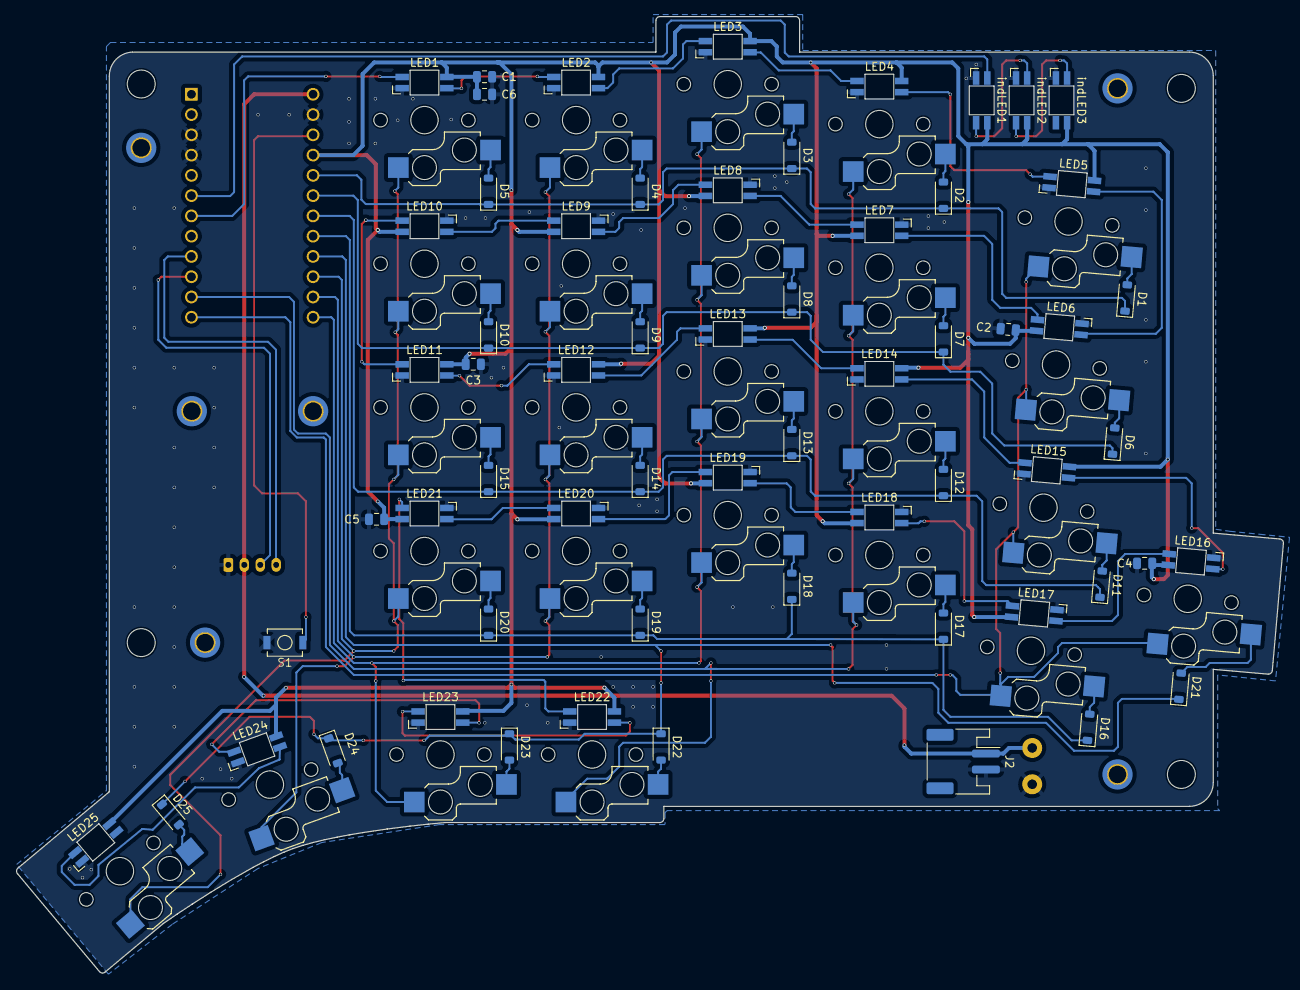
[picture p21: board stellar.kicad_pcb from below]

Board: 2 copper layers, 158.8 x 119.9 mm, 100 parts (68 on the bottom side), 69 nets.

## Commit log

2024-11-18 added left half
    [backlight.kicad_sch, keymatrix.kicad_sch, stellar.kicad_pcb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]
2024-11-18 [pcb] moved left halve to folder
    [backlight.kicad_sch, keymatrix.kicad_sch, stellar.kicad_pcb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]
2024-11-18 [pcb] removed backup file
2024-11-19 [pcb] moved to 'left' folder
    [backlight.kicad_sch, keymatrix.kicad_sch, stellar.kicad_pcb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]
2024-11-19 [pcb] initial right halve
    [keymatrix.kicad_sch, stellar.kicad_pcb, stellar.kicad_sch]
2024-11-20 [pcb] right half layout done
    [stellar.kicad_pcb]
2024-11-20 [pcb] right halve, more routing
    [backlight.kicad_sch, stellar.kicad_pcb]
2024-11-21 [pcb] final version, maybe
    [stellar.kicad_pcb]
2024-11-21 [pcb] production files
    [stellar-B_Cu.gbl, stellar-B_Mask.gbs, stellar-B_Paste.gbp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]
2024-12-01 [pcb] fixed logo and added J1 con 3D model
    [stellar.kicad_pcb, stellar.kicad_sch]
2024-12-01 [pcb] moved to PCB folder
    [backlight.kicad_sch, keymatrix.kicad_sch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]
2024-12-13 [pcb] updated paths to 3D models
    [stellar.kicad_pcb]
2024-12-15 [case] added left and right case step files
    [bottom_plate_left.step, bottom_plate_right.step, key_frame_left.step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]
2024-12-15 [zmk] added esc, ret, and tab to right halve
2024-12-31 [zmk] added print screen
2025-01-26 [zmk] combos changed
    Removed enter, escape, and tab from other layers. Added tab to the
    gaming layer. Changed copy and paste combos. Removed the no longer used
    combo to switch off the gaming layer.
2025-01-26 [zmk] added soft off and toggle gaming layer
    This adds a soft off behavior to shutdown the key board. Added a toggle
    for the gaming layer. Also removed the stop for stopping playing media.
2025-01-26 [case] added a reset button to bottom
    [bottom_plate_left.step, bottom_plate_right.step, reset_button_knob.step]
2025-01-26 [case] added a keyboard holder/travel case
    Added a nice holder and/or travel case to hold the two halves. I will
    iterate over this a bit, since the top of the two halve will rub
    together when put in a back pack.
    [keyboard_case.step]
2025-01-26 [doc] added PCB images, traces, and schematic PDFs
2025-02-05 [zmk] changed and added some combos
    * esc and ret now only on left hand
    * moved tab to LM3 and LM2 and allow LALT when hold
    * added horizontal combos right hand for bspc and del
    * added vertical combos right hand for colon and semi
2025-02-11 [zmk] added brackets to vertical combos
2025-02-12 [zmk] added more combos
    Changed some of the positions for the brackets and added some combos for
    often used symbols.
2026-10-14 feat(zmk): switched to qwerty
